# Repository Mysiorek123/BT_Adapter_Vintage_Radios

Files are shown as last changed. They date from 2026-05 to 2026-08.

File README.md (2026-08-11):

# Bluetooth Adapter for Vintage Radios

This project presents the design and implementation of a specialized Bluetooth adapter aimed at modernizing vintage radio receivers, such as the Polish Unitra Zodiak, while preserving their unique acoustic character. The hardware features a multi-stage power supply and signal isolation architecture, utilizing a bridge rectifier, high-capacity filtering, and a PS2561 optoisolator to eliminate hum and ground loops. 

# I/O Pinouts Description

- ~AC - AC Input Voltage (6,3V)
- J1 - Separated 1,2V DC Input
- J2 - Separated 1,2V Ground
- J3 - Bluetooth Power Supply (VCC)
- J4 - Bluetooth Ground (GND)

# Schematic Diagram
BT_Adapter Vintage Radios (2)

# PCB View

The physical implementation employs a double-sided PCB designed for a vertical "sandwich" stack configuration, ensuring full mechanical compatibility and efficient heat dissipation. 

image (2)
image (3)

# Components()
| Reference  | Footprint | Qty | Value / Description|
| :--- | :--- | :-: | :--- |
| **1** | J2 | SolderWire-0.1sqmm_1x01_D0.4mm_OD1mm | 1 | BT_VCC | |
| **2** | J1 | SolderWire-0.1sqmm_1x01_D0.4mm_OD1mm | 1 | 1V2_SEPARATED | |
| **3** | J3 | SolderWire-0.1sqmm_1x01_D0.4mm_OD1mm | 1 | BT_GND | |
| **4** | B1 | Diode_Bridge_19.0x3.5x10.0mm_P5.0mm | 1 | B40C2300-1500A | |
| **5** | C2, C4 | C_Axial_L3.8mm_D2.6mm_P7.50mm_Horizontal | 2 | 100nF | |
| **6** | U2 | TO-220-3_Vertical | 1 | LM7805 | |
| **7** | R2 | R_Axial_DIN0207_L6.3mm_D2.5mm_P7.62mm_Horizontal | 1 | 10k | |
| **8** | C3 | CP_Radial_D6.3mm_P2.50mm | 1 | 220uF | |
| **9** | I1 | SolderWire-0.1sqmm_1x02_P3.6mm_D0.4mm_OD1mm | 1 | AC | |
| **10** | R1 | R_Axial_DIN0207_L6.3mm_D2.5mm_P7.62mm_Horizontal | 1 | 220 | |
| **11** | Q1 | TO-220-3_Vertical | 1 | IRF620N | |
| **12** | C1 | CP_Radial_D10.0mm_P5.00mm | 1 | 2200uF | |
| **13** | U1 | DIP-4_W7.62mm | 1 | PS2561 | |

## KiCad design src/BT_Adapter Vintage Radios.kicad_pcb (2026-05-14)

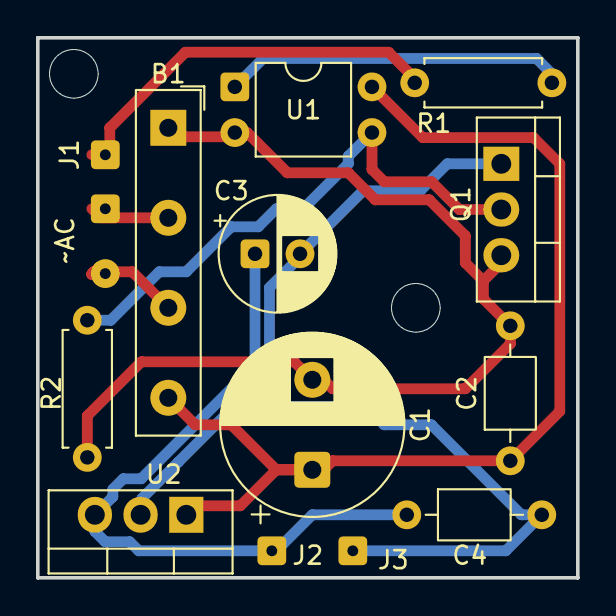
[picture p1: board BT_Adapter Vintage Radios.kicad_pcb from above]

Board: 2 copper layers, 30.0 x 30.0 mm, 14 parts (0 on the bottom side), 9 nets.

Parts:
B1: B40C2300-1500A; Diode_Bridge_19.0x3.5x10.0mm_P5.0mm
C1: 2200uF; CP_Radial_D10.0mm_P5.00mm
C2, C4: 100nF; C_Axial_L3.8mm_D2.6mm_P7.50mm_Horizontal
C3: 220uF; CP_Radial_D6.3mm_P2.50mm
I1: AC; SolderWire-0.1sqmm_1x02_P3.6mm_D0.4mm_OD1mm
J1: 1V2_SEPARATED; SolderWire-0.1sqmm_1x01_D0.4mm_OD1mm
J2: BT_VCC; SolderWire-0.1sqmm_1x01_D0.4mm_OD1mm
J3: BT_GND; SolderWire-0.1sqmm_1x01_D0.4mm_OD1mm
Q1: IRF620N; TO-220-3_Vertical
R1: 220; R_Axial_DIN0207_L6.3mm_D2.5mm_P7.62mm_Horizontal
R2: 10k; R_Axial_DIN0207_L6.3mm_D2.5mm_P7.62mm_Horizontal
U1: PS2561; DIP-4_W7.62mm
U2: LM7805; TO-220-3_Vertical

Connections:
GND: B1.1 (-), C1.2, C2.2, Q1.3 (S), R2.2, U1.2
unnamed: B1.2, I1.1
unnamed: B1.3, I1.2
unnamed: J1.1, R1.1
unnamed: C3.1, C4.1, J2.1, U2.3 (VO)
unnamed: C3.2, C4.2, J3.1, Q1.1 (D), U2.2 (GND)
unnamed: Q1.2 (G), R2.1, U1.3
unnamed: R1.2, U1.1
VCC: B1.4 (+), C1.1, C2.1, U1.4, U2.1 (VI)

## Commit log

2026-05-10 Uploaded first circuit diagram and PCB layout
    [BT_Adapter Vintage Radios.kicad_pcb, BT_Adapter Vintage Radios.kicad_sch]
2026-05-10 Moved project files to src folder
    [BT_Adapter Vintage Radios.kicad_pcb, BT_Adapter Vintage Radios.kicad_sch]
2026-05-14 Minor improvements
    [BT_Adapter Vintage Radios.kicad_pcb, BT_Adapter Vintage Radios.kicad_sch]
2026-08-11 PCB design changes
